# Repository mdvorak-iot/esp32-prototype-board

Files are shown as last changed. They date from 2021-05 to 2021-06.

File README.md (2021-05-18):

# esp32-prototype-board

EAGLE schematic for prototype board with 12V power input and all essentials.

Programmed and debugged using [ESP-PROG](https://github.com/espressif/esp-dev-kits/blob/master/esp-prog/docs/ESP-Prog_guide_en.md) interface.

## Renders

top

bottom

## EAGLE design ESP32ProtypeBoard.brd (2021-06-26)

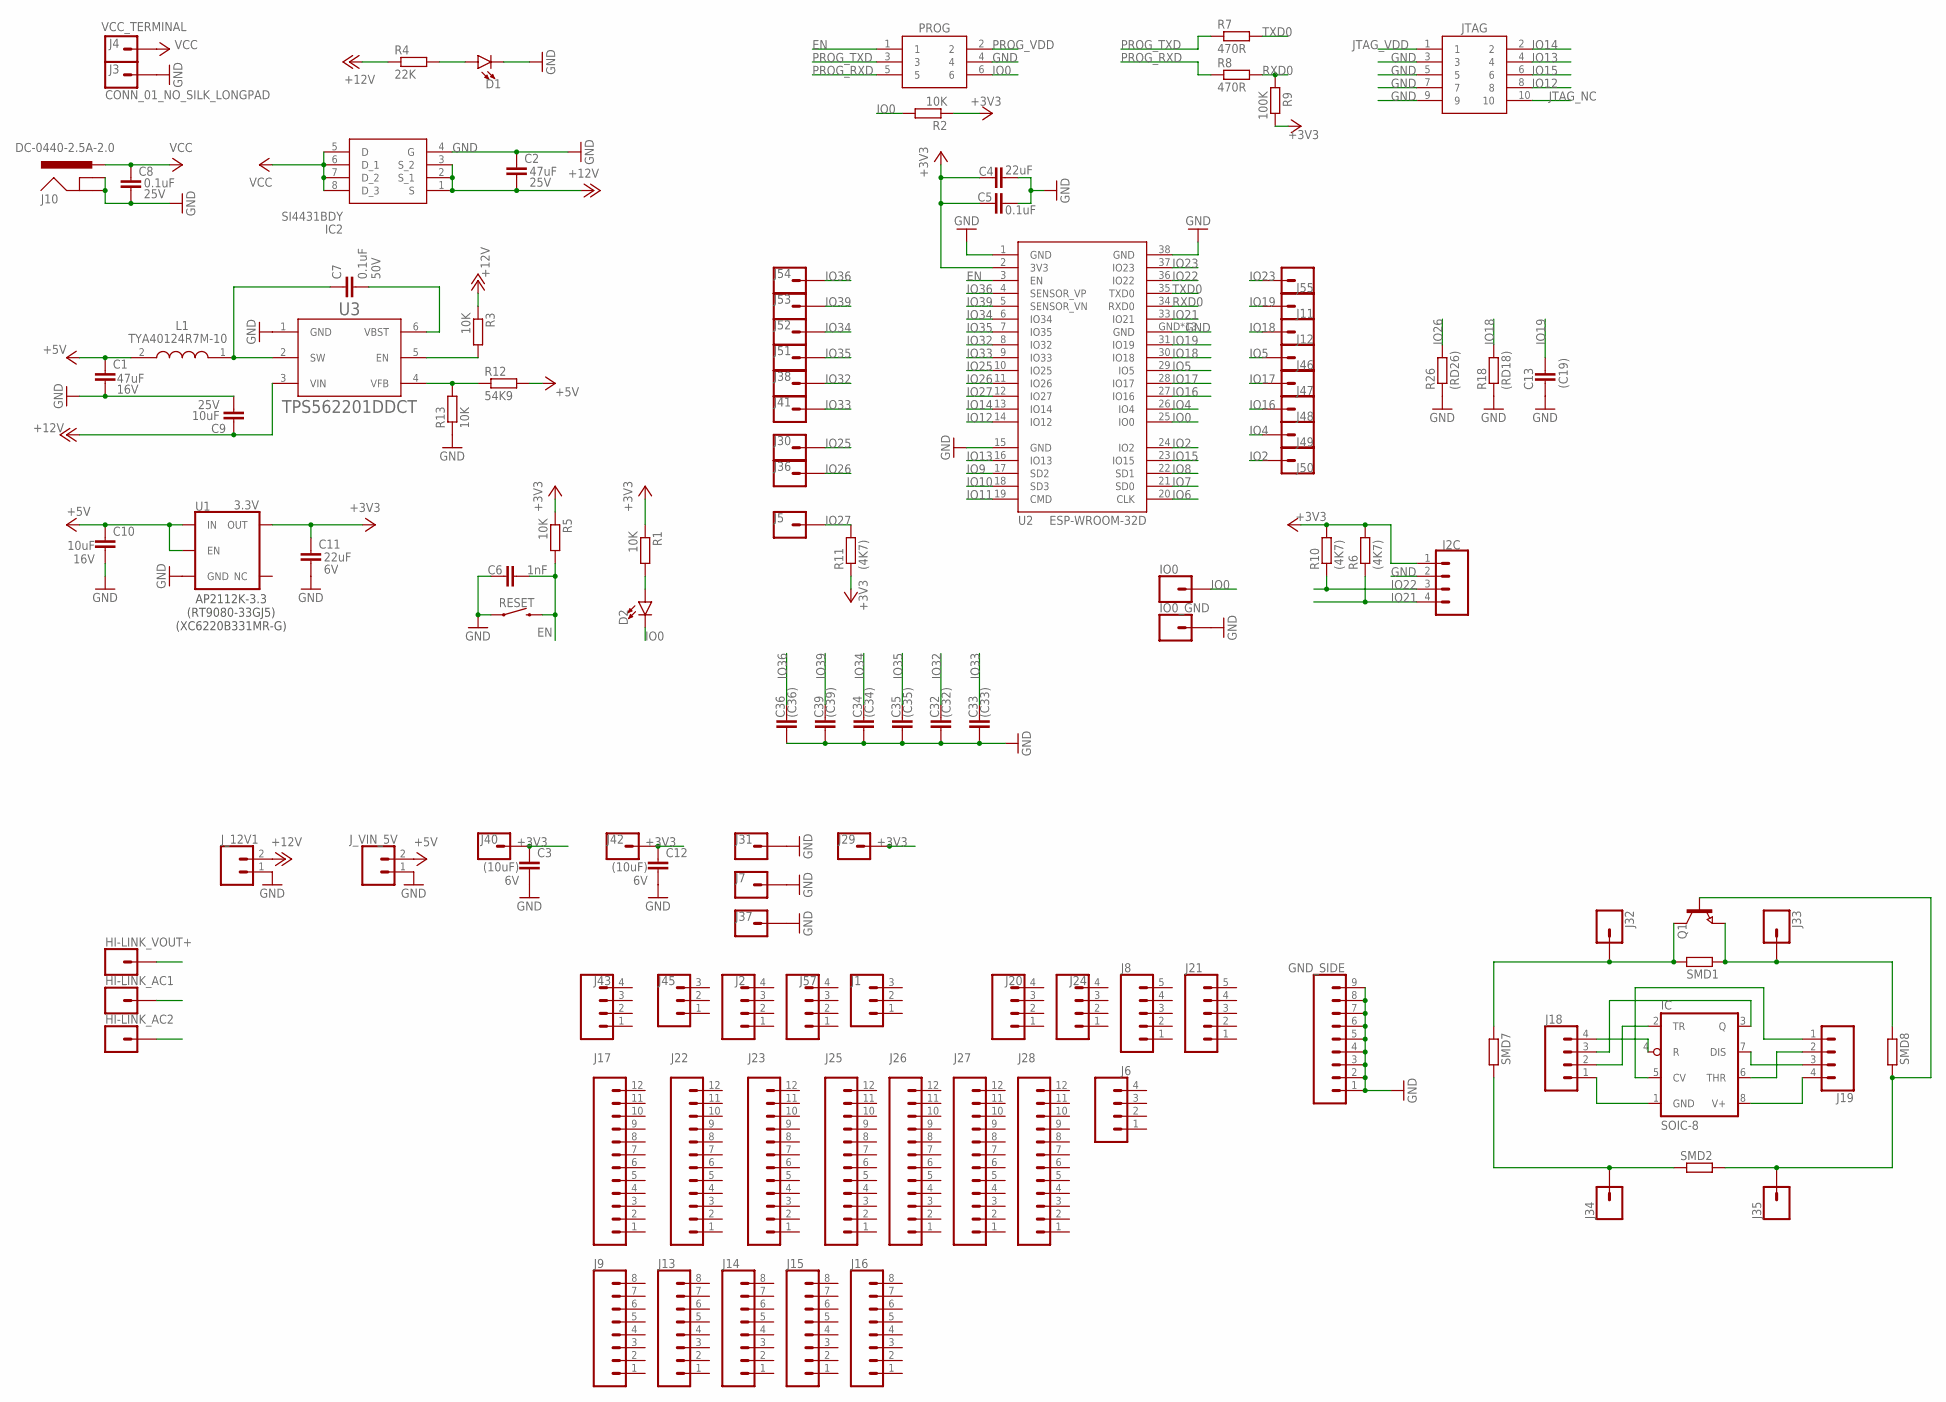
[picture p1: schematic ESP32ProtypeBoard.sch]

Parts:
C1: 47uF; C1206K; VOLTAGE 16V
C2: 47uF; C1206K; VOLTAGE 25V
C3, C12: (10uF); C0805K; VOLTAGE 6V
C4: 22uF; C0805K
C5: 0.1uF; C0805K
C6: 1nF; C0805K
C7: 0.1uF; C0805K; VOLTAGE 50V
C8: 0.1uF; C0805K; VOLTAGE 25V
C9: 10uF; C0805K; VOLTAGE 25V
C10: 10uF; C0805K; VOLTAGE 16V
C11: 22uF; C0805K; VOLTAGE 6V
C13: (C19); C0805K
C32: (C32); C0805K
C33: (C33); C0805K
C34: (C34); C0805K
C35: (C35); C0805K
C36: (C36); C0805K
C39: (C39); C0805K
D1: PWR; CHIPLED_0805
D2: GREEN; CHIPLED_0805
GND_SIDE: CONN_09NO_SILK; 1X09_NO_SILK
HI-LINK_AC1, HI-LINK_AC2: CONN_01PTH_NO_SILK_KIT; 1X01NS_KIT
HI-LINK_VOUT+: CONN_01PTH_NO_SILK_KIT; 1X01NS_KIT
I2C: CONN_041X04_NO_SILK; 1X04_NO_SILK
IC: SOIC-8; SO08
IC2: SI4431BDY; SOIC127P600X175-8N
IO0: CONN_01PTH_NO_SILK_KIT; 1X01NS_KIT
IO0_GND: CONN_01PTH_NO_SILK_YES_STOP; 1X01_NO_SILK
J1, J45: CONN_03_NO_SILK; 1X03_NO_SILK
J2, J6, J20, J24, J43, J57: CONN_04_NO_SILK; 1X04_NO_SILK
J3: CONN_01_NO_SILK_LONGPAD; 1X01_NO_SILK_LONGPAD
J4: VCC_TERMINAL; 1X01_NO_SILK_LONGPAD
J5, J7, J29, J30, J31, J36, J37, J38, J40, J41, J42, J51, J52, J53, J54: CONN_01_NO_SILK; 1X01_NO_SILK
J8, J21: CONN_05_NO_SILK; 1X05_NO_SILK
J9, J13, J14, J15, J16: CONN_08NO_SILK_FEMALE_PTH; 1X08_NO_SILK
J10: DC-0440-2.5A-2.0; DC044025A20
J11, J12, J32, J33, J34, J35, J46, J47, J48, J49, J50, J55: CONN_01PTH_NO_SILK_YES_STOP; 1X01_NO_SILK
J17, J22, J23, J25, J26, J27, J28: CONN_12NO_SILK; 1X12_NO_SILK
J18, J19: CONN_041X04_NO_SILK; 1X04_NO_SILK
JTAG: DC3-10-1P27
J_12V1: CONN_021X02_NO_SILK; 1X02_NO_SILK
J_VIN_5V: CONN_021X02_NO_SILK; 1X02_NO_SILK
L1: TYA40124R7M-10; INDPM4040X130N
PROG: DC3-06-1P27
Q1: NPN-TRANSISTOR_SOT23; SOT23
R1, R2, R3, R5, R13: 10K; R0805
R4: 22K; R0805
R6, R10, R11: (4K7); R0805
R7, R8: 470R; R0805
R9: 100K; R0805
R12: 54K9; R0805
R18: (RD18); R0805
R26: (RD26); R0805
RESET: RESET; TACTILE_SWITCH_SMD_4X3MM
SMD1, SMD2, SMD7, SMD8: RR1206; R1206
U1: 3.3V; SOT23-5
U2: ESP-WROOM-32D
U3: TPS562201DDCTTEXAS_INSTRUMENTS_TPS562201DDCT_0_0; TEXAS_INSTRUMENTS_TPS562201DDCT_0

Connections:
+3V3: C3.1, C4.1, C5.1, C11.1, C12.1, I2C.1, J29.1, J40.1, J42.1, R1.1, R2.1, R5.1, R6.2, R9.1, R10.2, R11.1, U1.5 (OUT), U2.2 (3V3)
+5V: C1.1, C10.1, J_VIN_5V.2, L1.2, R12.2, U1.1 (IN), U1.3 (EN)
+12V: C2.2, C9.1, IC2.1 (S), IC2.2 (S_1), IC2.3 (S_2), J_12V1.2, R3.1, R4.1, U3.3 (VIN)
AC1: HI-LINK_AC1.1
AC2: HI-LINK_AC2.1
D2A: D2.A, R1.2
EN: C6.2, PROG.1, R5.2, RESET.2, U2.3 (EN)
GND: C1.2, C2.1, C3.2, C4.2, C5.2, C6.1, C8.2, C9.2, C10.2, C11.2, C12.2, C13.2, C32.1, C33.1, C34.1, C35.1, C36.1, C39.1, D1.C, GND_SIDE.1, GND_SIDE.2, GND_SIDE.3, GND_SIDE.4, GND_SIDE.5, GND_SIDE.6, GND_SIDE.7, GND_SIDE.8, GND_SIDE.9, I2C.2, IC2.4 (G), IO0_GND.1, J3.1, J7.1, J10.2 (GND), J10.3 (GNDBREAK), J31.1, J37.1, JTAG.3, JTAG.5, JTAG.7, JTAG.9, J_12V1.1, J_VIN_5V.1, PROG.4, R13.1, R18.1, R26.1, RESET.1, U1.2 (GND), U2.1 (GND), U2.15 (GND), U2.38 (GND), U2.GND, U2.GND_1 (GND), U2.GND_2 (GND), U2.GND_3 (GND), U2.GND_4 (GND), U2.GND_5 (GND), U2.GND_6 (GND), U2.GND_7 (GND), U2.GND_8 (GND), U2.GND_9 (GND), U2.GND_10 (GND), U2.GND_11 (GND), U2.GND_12 (GND), U3.1 (GND)
IO0: D2.C, IO0.1, PROG.6, R2.2, U2.25 (IO0)
IO2: J50.1, U2.24 (IO2)
IO4: J49.1, U2.26 (IO4)
IO5: J46.1, U2.29 (IO5)
IO6: U2.20 (CLK)
IO7: U2.21 (SD0)
IO8: U2.22 (SD1)
IO9: U2.17 (SD2)
IO10: U2.18 (SD3)
IO11: U2.19 (CMD)
IO12: JTAG.8, U2.14 (IO12)
IO13: JTAG.4, U2.16 (IO13)
IO14: JTAG.2, U2.13 (IO14)
IO15: JTAG.6, U2.23 (IO15)
IO16: J48.1, U2.27 (IO16)
IO17: J47.1, U2.28 (IO17)
IO18: J12.1, R18.2, U2.30 (IO18)
IO19: C13.1, J11.1, U2.31 (IO19)
IO21: I2C.4, R6.1, U2.33 (IO21)
IO22: I2C.3, R10.1, U2.36 (IO22)
IO23: J55.1, U2.37 (IO23)
IO25: J30.1, U2.10 (IO25)
IO26: J36.1, R26.2, U2.11 (IO26)
IO27: J5.1, R11.2, U2.12 (IO27)
IO32: C32.2, J38.1, U2.8 (IO32)
IO33: C33.2, J41.1, U2.9 (IO33)
IO34: C34.2, J52.1, U2.6 (IO34)
IO35: C35.2, J51.1, U2.7 (IO35)
IO36: C36.2, J54.1, U2.4 (SENSOR_VP)
IO39: C39.2, J53.1, U2.5 (SENSOR_VN)
JTAG_NC: JTAG.10
JTAG_VDD: JTAG.1
unnamed: IC.7 (DIS), J19.3
unnamed: IC.6 (THR), J19.2
unnamed: IC.1 (GND), J18.1
unnamed: IC.2 (TR), J18.2
unnamed: IC.3 (Q), J18.3
unnamed: IC.4 (R), J18.4
unnamed: IC.5 (CV), J19.1
unnamed: IC.8 (V+), J19.4
unnamed: J34.1, SMD2.1, SMD7.2
unnamed: J35.1, Q1.1 (B), SMD2.2, SMD8.2
unnamed: J32.1, Q1.3 (C), SMD1.2, SMD7.1
unnamed: J33.1, Q1.2 (E), SMD1.1, SMD8.1
PROG_RXD: PROG.5, R8.1
PROG_TXD: PROG.3, R7.1
PROG_VDD: PROG.2
PWR_LED: D1.A, R4.2
RXD0: R8.2, R9.2, U2.34 (RXD0)
SW: C7.1, L1.1, U3.2 (SW)
TXD0: R7.2, U2.35 (TXD0)
VBST: C7.2, U3.6 (VBST)
VCC: C8.1, IC2.5 (D), IC2.6 (D_1), IC2.7 (D_2), IC2.8 (D_3), J4.1, J10.1 (PWR)
VEN: R3.2, U3.5 (EN)
VFB: R12.1, R13.2, U3.4 (VFB)

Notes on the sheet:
AP2112K-3.3 (RT9080-33GJ5) (XC6220B331MR-G)

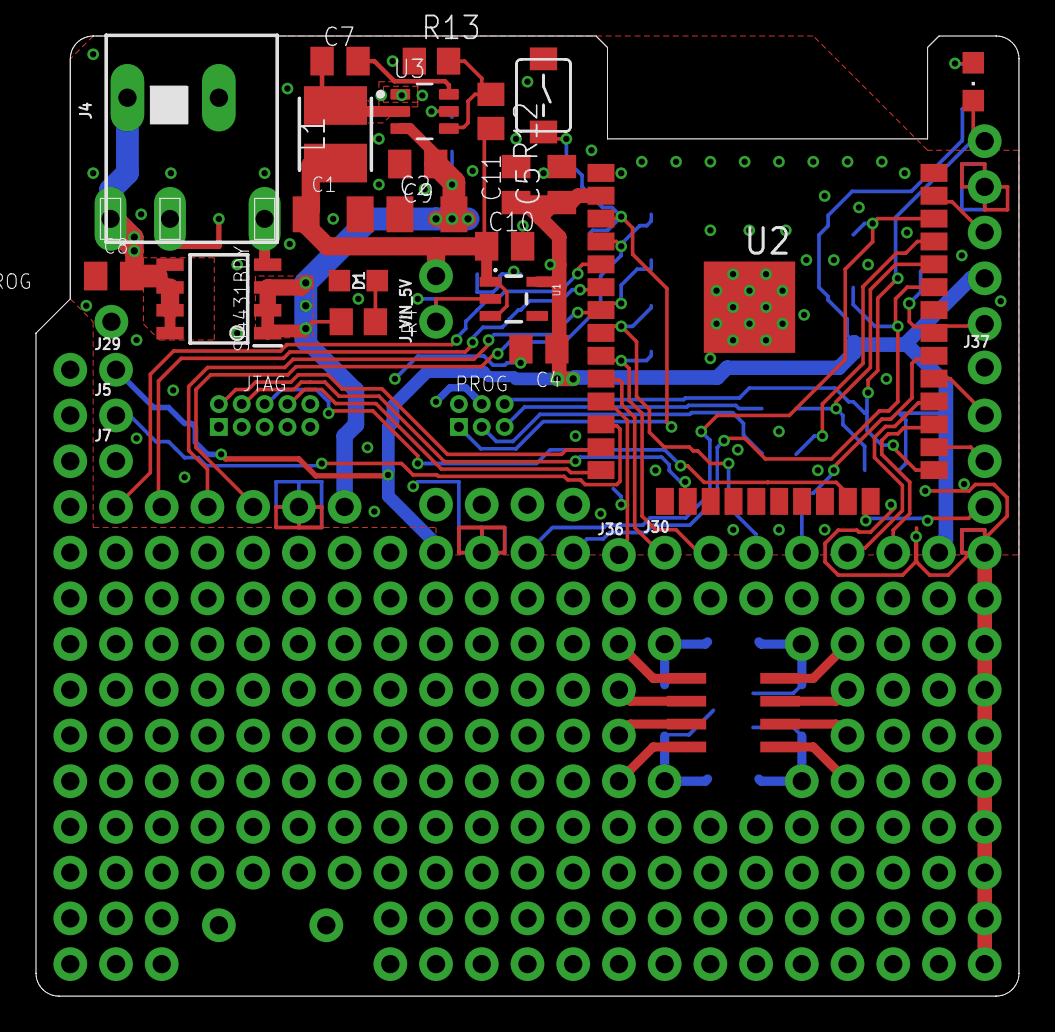
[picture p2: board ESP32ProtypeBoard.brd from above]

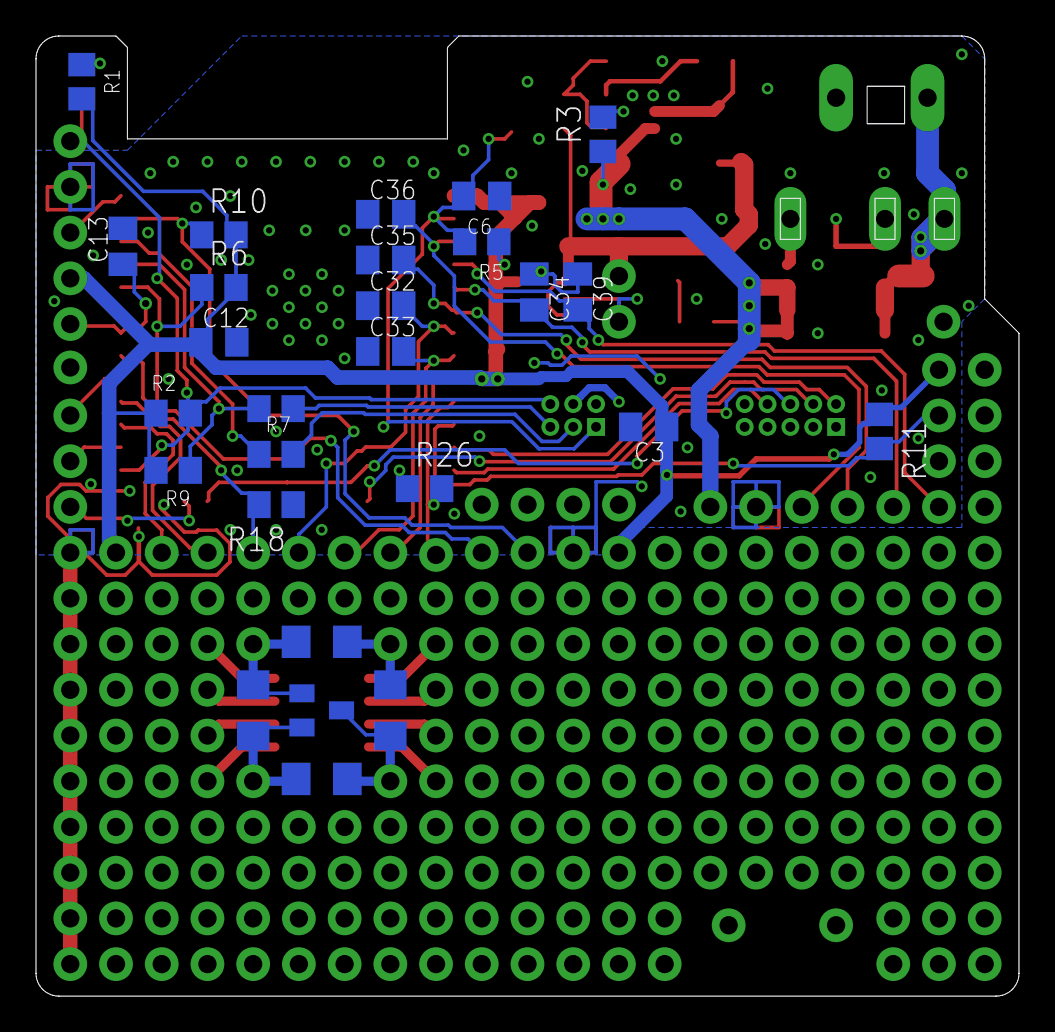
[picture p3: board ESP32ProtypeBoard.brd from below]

Board: 2 copper layers, 54.6 x 53.3 mm, 113 parts (30 on the bottom side), 52 nets.

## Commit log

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2018-10-29 More complete silk and complete diagram
    [ESP32ProtypeBoard.brd, ESP32ProtypeBoard.sch]
2018-10-29 Silk about flash modes
    [ESP32ProtypeBoard.brd, ESP32ProtypeBoard.sch]
2018-10-29 Different flash mode notation
    [ESP32ProtypeBoard.brd, ESP32ProtypeBoard.sch]
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2018-10-29 Moved npn transistor to bottom
    Moved signature
    Updated libs
    [ESP32ProtypeBoard.brd, ESP32ProtypeBoard.sch]
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2018-10-29 moved mode info text
    [ESP32ProtypeBoard.brd]
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2018-10-31 Removed hints about reset modes
    [ESP32ProtypeBoard.brd, ESP32ProtypeBoard.sch]
2018-10-31 Moved IO0 pinout, added pins for easy DS20B18 use
    [ESP32ProtypeBoard.brd, ESP32ProtypeBoard.sch]
2018-10-31 Final project with electrolytic caps
    [ESP32ProtypeBoard.brd, ESP32ProtypeBoard.sch]
2018-10-31 22uf cap, pad for gnd
    [ESP32ProtypeBoard.brd, ESP32ProtypeBoard.sch]
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2018-11-01 Renamed wierd bottom pins to numbers
    [ESP32ProtypeBoard.brd, ESP32ProtypeBoard.sch]
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2018-11-01 Completely new layout of the board
    [ESP32ProtypeBoard.brd, ESP32ProtypeBoard.sch]
2018-11-01 Work in progress on 1.1
    [ESP32ProtypeBoard.brd, ESP32ProtypeBoard.sch]
2018-11-01 Fixed uart pin order
    [ESP32ProtypeBoard.brd, ESP32ProtypeBoard.sch]
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2018-11-02 Moving around some pins
    [ESP32ProtypeBoard.brd, ESP32ProtypeBoard.sch]
2018-11-02 Fixed silk
    [ESP32ProtypeBoard.brd]
2018-11-02 Fixed some stubs
    [ESP32ProtypeBoard.brd]
2018-11-02 Replaced VCC IN pins to accomodate large screw terminal
    Some more silk changes
    [ESP32ProtypeBoard.brd, ESP32ProtypeBoard.sch]
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2018-11-11 Schema reordered for easier reuse
    [ESP32ProtypeBoard.brd, ESP32ProtypeBoard.sch]
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2019-01-13 Removed long-press flash mode
    [ESP32ProtypeBoard.brd, ESP32ProtypeBoard.sch]
2019-01-14 Added connections for side empty pins
    [ESP32ProtypeBoard.brd, ESP32ProtypeBoard.sch]
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2019-01-14 Moved controls under ESP
    [ESP32ProtypeBoard.brd]
2019-01-14 Improved wiring of power parts a little, reorganized capacitors
    [ESP32ProtypeBoard.brd, ESP32ProtypeBoard.sch]
2019-01-15 Moved input MOSFET, added pwr diode
    [ESP32ProtypeBoard.brd, ESP32ProtypeBoard.sch]
2019-01-15 Fixed some silk, improved DTR line, moved EN capacitor
    [ESP32ProtypeBoard.brd]
2019-01-15 Moved REG close to ESP to allow very small cutout
    [ESP32ProtypeBoard.brd, ESP32ProtypeBoard.sch]
2019-01-15 Rewired pins under ESP etc
    [ESP32ProtypeBoard.brd, ESP32ProtypeBoard.sch]
2019-01-16 Moving around power pins to save space
    [ESP32ProtypeBoard.brd, ESP32ProtypeBoard.sch]
2019-01-16 Smarter space extra SMD, completed pinout
    [ESP32ProtypeBoard.brd, ESP32ProtypeBoard.sch]
2019-01-16 FINAL version
    Fixed all silk, moved optional cap
    [ESP32ProtypeBoard.brd, ESP32ProtypeBoard.sch]
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2019-01-23 Replaced holes with large vias
    Larger power trace
    45° corners around antenna
    [ESP32ProtypeBoard.brd]
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2019-12-06 Worked out some TODOs, unfinished board
    LED resistors
    Removed PPTC1
    [ESP32ProtypeBoard.brd, ESP32ProtypeBoard.sch]
2020-05-15 WIP on next gen
    [ESP32ProtypeBoard.brd, ESP32ProtypeBoard.sch]
2020-05-15 WIP on new layout
    [ESP32ProtypeBoard.brd, ESP32ProtypeBoard.sch]
2020-05-15 WIP: almost all essentials wired
    [ESP32ProtypeBoard.brd, ESP32ProtypeBoard.sch]
2020-05-16 WIP fixed many bugs, added JTAG compatible ordering
    [ESP32ProtypeBoard.brd, ESP32ProtypeBoard.sch]
2020-05-16 WIP all wired, TODOs left
    [ESP32ProtypeBoard.brd, ESP32ProtypeBoard.sch]
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2020-05-17 Replaced all 6mil traces with 8mil
    All wired
    [ESP32ProtypeBoard.brd]
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2020-05-17 Fixed outline, removed 2 mount holes, moved them, silk tuning
    [ESP32ProtypeBoard.brd, ESP32ProtypeBoard.sch]
2020-05-17 Tuned silk, looks ready
    [ESP32ProtypeBoard.brd, ESP32ProtypeBoard.sch]
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2020-05-18 Added place for smd capacitor under 220uF electrolytic
    To support at least some cap in space constrained situations
    [ESP32ProtypeBoard.brd, ESP32ProtypeBoard.sch]
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2020-05-18 Fixed stub
    [ESP32ProtypeBoard.brd]
2020-05-18 Fixed traces under esp (touched gnd), moved cooling vias
    and some more silk tuning
    [ESP32ProtypeBoard.brd, ESP32ProtypeBoard.sch]
2020-05-19 Switched IO21 and IO0, IO0 is now KIT with covered top side
    Added top silk for all kit holes
    Minor traces improvements
    Stronger GND on the side
    [ESP32ProtypeBoard.brd, ESP32ProtypeBoard.sch]
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2020-05-19 rewired traces around new GND, improved GND routing
    changed polygon width to 8 for wider thermals and less obscure corners
    [ESP32ProtypeBoard.brd]
2020-05-19 fixed last 6 wide trace to 8, moved one via to pass gnd
    [ESP32ProtypeBoard.brd]
2020-05-19 improved GND routing
    now is both layers completely connected
    improved 3v3 trace as well
    [ESP32ProtypeBoard.brd]
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2020-05-19 Added place for smd logic level converter
    used free space
    fixed silk in bottom smd placeholder
    [ESP32ProtypeBoard.brd, ESP32ProtypeBoard.sch]
2020-05-19 removed extra gnd, added dot as orientation mark
    [ESP32ProtypeBoard.brd, ESP32ProtypeBoard.sch]
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2021-05-01 Replaced buck converter module with custom curcuit
    Using ACT4088US-T for 5V rail
    [ESP32ProtypeBoard.brd, ESP32ProtypeBoard.sch]
2021-05-01 Replaced all resistors with 0805 variants
    [ESP32ProtypeBoard.brd, ESP32ProtypeBoard.sch]
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2021-05-01 Using esp-prog as programming interface
    Removed RTS/DTS reset boot logic
    [ESP32ProtypeBoard.brd, ESP32ProtypeBoard.sch]
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2021-05-02 Replaced switch, fixed errors
    [ESP32ProtypeBoard.brd, ESP32ProtypeBoard.sch]
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2021-05-05 Experimenting with another layout: reset in middle
    [ESP32ProtypeBoard.brd, ESP32ProtypeBoard.sch]
2021-05-05 Replaced leds with 0805
    [ESP32ProtypeBoard.brd, ESP32ProtypeBoard.sch]
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2021-05-14 replaced LDO with RT9080-33GJ5 (smaller)
    more expensive, only 600mA
    better buck converter position
    [ESP32ProtypeBoard.brd, ESP32ProtypeBoard.sch]
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2021-05-15 A lot of wirings, no terminals in place yet
    Power cascade looks good
    [ESP32ProtypeBoard.brd, ESP32ProtypeBoard.sch]
2021-05-15 added missing 3v3 connection
    [ESP32ProtypeBoard.brd]
2021-05-15 added missing FB connection
    [ESP32ProtypeBoard.brd]
2021-05-15 Fixed terminal position, improved gnd traces
    [ESP32ProtypeBoard.brd, ESP32ProtypeBoard.sch]
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2021-05-15 first data lines, added new VIN pin closer
    [ESP32ProtypeBoard.brd, ESP32ProtypeBoard.sch]
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2021-05-16 moved all gpios a little down to fit below esp
    [ESP32ProtypeBoard.brd, ESP32ProtypeBoard.sch]
2021-05-16 fixed traces and silk after move
    [ESP32ProtypeBoard.brd]
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2021-05-16 fixed some errors
    [ESP32ProtypeBoard.brd]
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2021-05-16 removed gnd plain from breadboard on left side
    [ESP32ProtypeBoard.brd, ESP32ProtypeBoard.sch]
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2021-05-16 flipped HLK pads
    [ESP32ProtypeBoard.brd]
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2021-05-16 missing silk line
    [ESP32ProtypeBoard.brd]
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2021-05-17 fixed corner dimensions
    [ESP32ProtypeBoard.brd]
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2021-06-16 Improved TPS562201DDCTT lbr, using it in design
    WIP: Schematic only, no layout yet
    [ESP32ProtypeBoard.brd, ESP32ProtypeBoard.sch]
2021-06-16 Removed restrict from TPS562201 lbr
    WIP: converter layout
    [ESP32ProtypeBoard.brd, ESP32ProtypeBoard.sch]
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2021-06-17 Moved breadboard one step down
    making more space between wroom and pins
    silk fits better
    [ESP32ProtypeBoard.brd]
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2021-06-17 Removed bss138 placeholder, moved IO27 to left
    Created space for DS18B20
    Moved IO25 and 26 one place left
    [ESP32ProtypeBoard.brd, ESP32ProtypeBoard.sch]
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2021-06-18 added pull-ups to I2C and IO27, pull downs and capacitors to ADC
    [ESP32ProtypeBoard.brd, ESP32ProtypeBoard.sch]
2021-06-18 removed PPTC for 3V3 out
    using rail directly, hopefully LDO will handle short curcuit
    [ESP32ProtypeBoard.brd, ESP32ProtypeBoard.sch]
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2021-06-21 Improved ADC caps layout, improved GND plane around
    [ESP32ProtypeBoard.brd]
2021-06-21 Fixed silk for all placed components
    [ESP32ProtypeBoard.brd, ESP32ProtypeBoard.sch]
2021-06-21 Turned DC jack connector facing up again
    It was non-sense to face it cut-out side
    Historically all versions had it facing top
    Adjusted everything around
    [ESP32ProtypeBoard.brd]
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2021-06-23 improved layout across the board
    avoid acute trace angles for pads
    [ESP32ProtypeBoard.brd]
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2021-06-26 added extra optional cap for IO19
    for addditional switch for SW reset
    [ESP32ProtypeBoard.brd, ESP32ProtypeBoard.sch]
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

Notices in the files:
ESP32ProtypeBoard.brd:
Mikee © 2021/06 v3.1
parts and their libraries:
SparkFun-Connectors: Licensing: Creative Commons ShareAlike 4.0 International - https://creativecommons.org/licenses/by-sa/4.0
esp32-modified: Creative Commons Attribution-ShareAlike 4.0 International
